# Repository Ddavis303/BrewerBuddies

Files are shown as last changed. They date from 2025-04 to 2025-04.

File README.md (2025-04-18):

# Brew Buddy – IoT Brewing Analytics System
## Overview
The Brew Buddy is an IoT-based system designed to help brewers—especially small craft and home brewers—monitor essential brewing parameters in real time. Using a combination of sensors and an Argon microcontroller, the system collects temperature, pH, specific gravity (via weight), and volume (via distance), displays the data on a web dashboard, and sends text alerts and email alerts when any readings fall outside predefined thresholds.
This project was developed as a capstone for an IoT Rapid Prototyping course and serves as a working proof-of-concept for a scalable tech solution in the brewing industry.
---
## Features
- Live data readings from brewing vessels
- Remote monitoring via dashboard
- SMS notifications when values exceed thresholds
- Simulated homebrew setup for testing and demonstration
---
## Sensors & Components
- *Argon* – Microcontroller
- **DS18B20** – Digital temperature sensor
- **pH Sensor** – Analog pH probe
- **Load Cell + HX711** – For measuring weight/specific gravity
- **VL53L0X TOF Sensor** – For estimating volume via liquid height
- **Breadboard**, **jumper wires**, **power supply**
- **Zapier** 
- **Adafruit Dashboard** 
---
## How It Works
1. Sensors are connected to the Argon and calibrated for the brewing environment.
2. Readings are taken at regular intervals and sent to the cloud.
3. A dashboard displays live data for each sensor.
4. If a reading moves outside acceptable parameters (e.g., temperature too high), an SMS alert is triggered.
---
## Setup Instructions
1. **Assemble the hardware**
Connect each sensor to the Argon as specified in the wiring diagram (included below or in the gallery).
2. **Flash the Argon*
Upload the code using Arduino IDE or PlatformIO. Install required libraries:
- `OneWire`
- `DallasTemperature`
- `HX711`
- `VL53L0X`
- Any network/messaging libraries needed
3. **Configure the backend**
- Set up a Zappier for email and text alerts
- Link your Argon code to your backend using API keys
4. **Calibrate sensors**
Run test readings and calibrate the sensors based on your brewing environment.
5. **Monitor & Brew!**
Watch your live dashboard and relax—alerts will notify you of any problems.
---
## Future Improvements
- Batch tracking and historical analytics
- Predictive alerts based on trend data
- Integration with commercial brewing systems
- Mobile app interface
---
## Credits
**Built by:**
- Dillon Davis
- Victor Roman
*Capstone Team – IoT Rapid Prototyping, April 2025*

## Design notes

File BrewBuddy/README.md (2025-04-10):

# BrewBuddy

This firmware project was created using [Particle Developer Tools](https://www.particle.io/developer-tools/) and is compatible with all [Particle Devices](https://www.particle.io/devices/).

Feel free to replace this README.md file with your own content, or keep it for reference.

## Table of Contents
- [Introduction](#introduction)
- [Prerequisites To Use This Template](#prerequisites-to-use-this-repository)
- [Getting Started](#getting-started)
- [Particle Firmware At A Glance](#particle-firmware-at-a-glance)
  - [Logging](#logging)
  - [Setup and Loop](#setup-and-loop)
  - [Delays and Timing](#delays-and-timing)
  - [Testing and Debugging](#testing-and-debugging)
  - [GitHub Actions (CI/CD)](#github-actions-cicd)
  - [OTA](#ota)
- [Support and Feedback](#support-and-feedback)
- [Version](#version)

## Introduction

For an in-depth understanding of this project template, please refer to our [documentation](https://docs.particle.io/firmware/best-practices/firmware-template/).

## Prerequisites To Use This Repository

To use this software/firmware on a device, you'll need:

- A [Particle Device](https://www.particle.io/devices/).
- Windows/Mac/Linux for building the software and flashing it to a device.
- [Particle Development Tools](https://docs.particle.io/getting-started/developer-tools/developer-tools/) installed and set up on your computer.
- Optionally, a nice cup of tea (and perhaps a biscuit).

## Getting Started

1. While not essential, we recommend running the [device setup process](https://setup.particle.io/) on your Particle device first. This ensures your device's firmware is up-to-date and you have a solid baseline to start from.

2. If you haven't already, open this project in Visual Studio Code (File -> Open Folder). Then [compile and flash](https://docs.particle.io/getting-started/developer-tools/workbench/#cloud-build-and-flash) your device. Ensure your device's USB port is connected to your computer.

3. Verify the device's operation by monitoring its logging output:
    - In Visual Studio Code with the Particle Plugin, open the [command palette](https://docs.particle.io/getting-started/developer-tools/workbench/#particle-commands) and choose "Particle: Serial Monitor".
    - Or, using the Particle CLI, execute:
    ```
    particle serial monitor --follow
    ```

4. Uncomment the code at the bottom of the cpp file in your src directory to publish to the Particle Cloud! Login to console.particle.io to view your devices events in real time.

5. Customize this project! For firmware details, see [Particle firmware](https://docs.particle.io/reference/device-os/api/introduction/getting-started/). For information on the project's directory structure, visit [this link](https://docs.particle.io/firmware/best-practices/firmware-template/#project-overview).

## Particle Firmware At A Glance

### Logging

The firmware includes a [logging library](https://docs.particle.io/reference/device-os/api/logging/logger-class/). You can display messages at different levels and filter them:

```
Log.trace("This is trace message");
Log.info("This is info message");
Log.warn("This is warn message");
Log.error("This is error message");
```

### Setup and Loop

Particle projects originate from the Wiring/Processing framework, which is based on C++. Typically, one-time setup functions are placed in `setup()`, and the main application runs from the `loop()` function.

For advanced scenarios, explore our [threading support](https://docs.particle.io/firmware/software-design/threading-explainer/).

### Delays and Timing

By default, the setup() and loop() functions are blocking whilst they run, meaning that if you put in a delay, your entire application will wait for that delay to finish before anything else can run. 

For techniques that allow you to run multiple tasks in parallel without creating threads, checkout the code example [here](https://docs.particle.io/firmware/best-practices/firmware-template/).

(Note: Although using `delay()` isn't recommended for best practices, it's acceptable for testing.)

### Testing and Debugging

For firmware testing and debugging guidance, check [this documentation](https://docs.particle.io/troubleshooting/guides/build-tools-troubleshooting/debugging-firmware-builds/).

### GitHub Actions (CI/CD)

This project provides a YAML file for GitHub, automating firmware compilation whenever changes are pushed. More details on [Particle GitHub Actions](https://docs.particle.io/firmware/best-practices/github-actions/) are available.

### OTA

To learn how to utilize Particle's OTA service for device updates, consult [this documentation](https://docs.particle.io/getting-started/cloud/ota-updates/).

Test OTA with the 'Particle: Cloud Flash' command in Visual Studio Code or the CLI command 'particle flash'!

This firmware supports binary assets in OTA packages, allowing the inclusion of audio, images, configurations, and external microcontroller firmware. More details are [here](https://docs.particle.io/reference/device-os/api/asset-ota/asset-ota/).

## Support and Feedback

For support or feedback on this template or any Particle products, please join our [community](https://community.particle.io)!

## Version

Template version 1.0.2

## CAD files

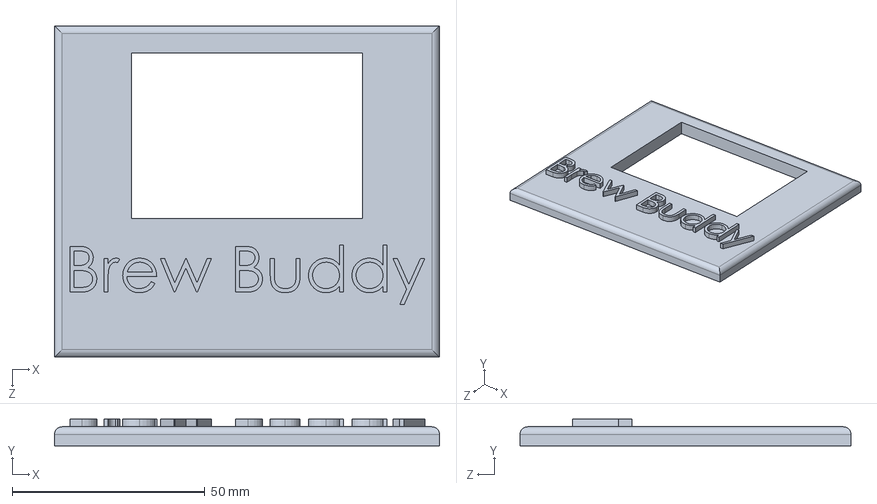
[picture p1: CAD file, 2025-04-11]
STL_SolidWorksFiles/BrewBuddyLid.SLDPRT
100.0 x 7.00 x 86.0 mm

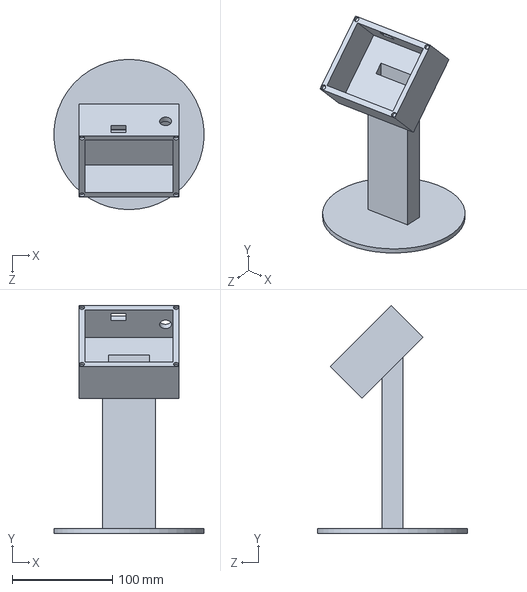
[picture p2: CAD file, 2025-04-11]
STL_SolidWorksFiles/BrewBuddyCase.SLDPRT
149.7 x 227.6 x 150.0 mm

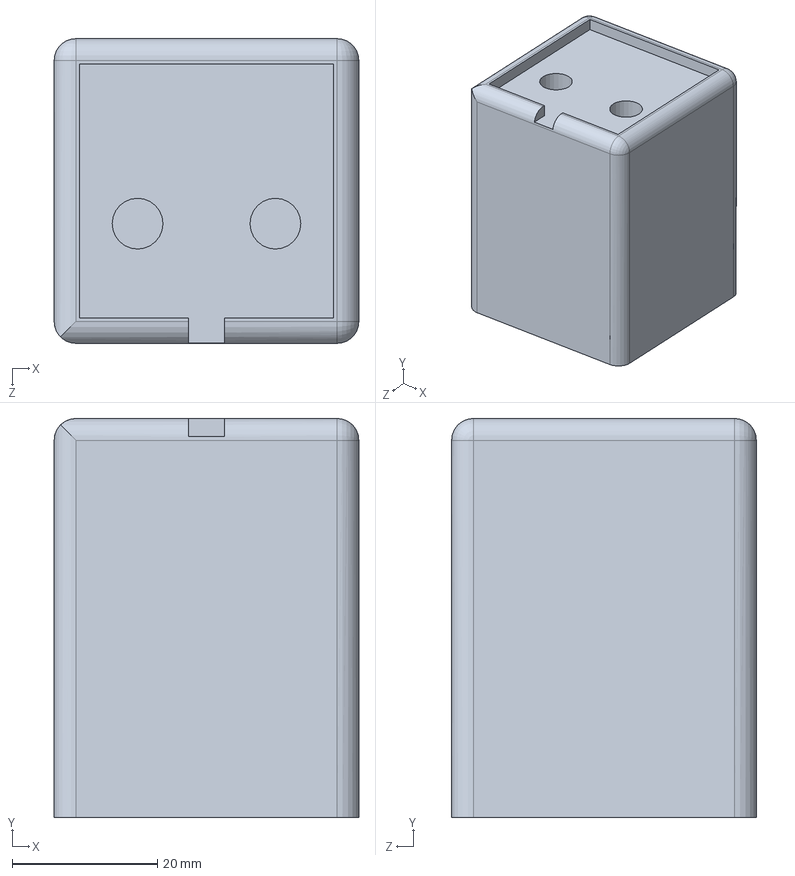
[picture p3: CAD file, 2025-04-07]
STL_SolidWorksFiles/BbLegStand.SLDPRT
42.0 x 55.0 x 42.0 mm

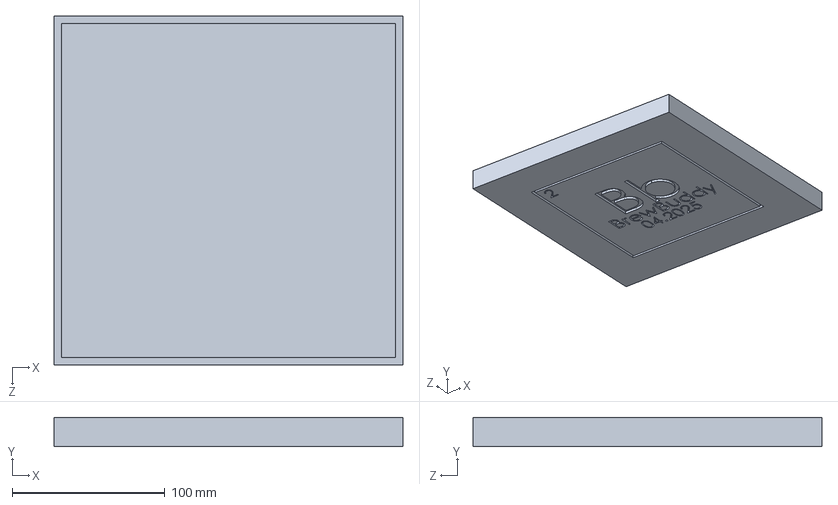
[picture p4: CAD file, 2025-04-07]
STL_SolidWorksFiles/ScaleLidBB.SLDPRT
228.6 x 19.1 x 228.6 mm

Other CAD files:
STL_SolidWorksFiles/BrewBuddyLogo.SLDPRT
STL_SolidWorksFiles/BbLegStand.3mf
STL_SolidWorksFiles/BbLegStand.STL
STL_SolidWorksFiles/BrewBuddyCase.STL
STL_SolidWorksFiles/BrewBuddyLid.STL
STL_SolidWorksFiles/ScaleLidBB.3mf
STL_SolidWorksFiles/ScaleLidBB.STL

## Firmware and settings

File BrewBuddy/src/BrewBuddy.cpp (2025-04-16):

/* 
 * Project Brew Buddy
 * Author: Victor Roman & Dillon Davis
 * Date: 4/10/25  
 * For comprehensive documentation and examples, please visit:
 * https://docs.particle.io/firmware/best-practices/firmware-template/
 */

// Include Particle Device OS APIs
#include "Particle.h"
#include "HX711.h"
#include "DS18B20.h"
#include "OneWire.h"
//#include "Adafruit_SSD1306.h"
//#include "Adafruit_GFX.h"
#include "Adafruit_MQTT.h"
#include "Adafruit_MQTT/Adafruit_MQTT_SPARK.h"
#include "Adafruit_MQTT/Adafruit_MQTT.h"
#include "credentials.h"
#include "Adafruit_VL53L0X.h"
#include "SPI.h"
#include "Adafruit_ILI9341.h"
#include "logo.h"

TCPClient theClient;
Adafruit_MQTT_SPARK mqtt(&theClient, AIO_SERVER, AIO_SERVERPORT, AIO_USERNAME, AIO_KEY);

//Variables
const int MAXRETRY = 4;
const uint32_t msSAMPLE_INTERVAL = 2500;
const uint32_t msMETRIC_PUBLISH = 10000;
uint32_t lastTime = 0;
uint32_t lastHour = 0;

const int16_t dsVCC = D3;
const int16_t dsData = D2;
//const int16_t dsGND = D4;

char szInfo[64];
double celsius;
double fahrenheit;
uint32_t msLastMetric;
uint32_t msLastSample;
const int PHPIN = A1;
float pH;
const int OLED_RESET = -1;
float acidVoltage = 2070;
float neutralVoltage = 1580;
float voltage, slope, intercept, ph = 25;

const float CALFACTOR=5.45;
const int SAMPLES=10;
float weight, rawData, calibration, liquidWeight;
int offset;

const float H20DENSITY = 1;//g/cm^3
const float RADIUS = 10.5;//cm
float gallons, volume, height, density, specificGravity;

const int TFT_DC = D5;
const int TFT_CS = D4;

// int col[8] = {tft.color565(155, 0, 50),
//               tft.color565(170, 30, 80),
//               tft.color565(195, 60, 110),
//               tft.color565(215, 90, 140),
//               tft.color565(230, 120, 170),
//               tft.color565(250, 150, 200),
//               tft.color565(255, 180, 220),
//               tft.color565(255, 210, 240)
//             };


//const float PI = 3.14159265358979323846;
//Functions
void MQTT_connect();
bool MQTT_ping();
void getTemp();
void publishData();
float getPH();
//void showmsgXY(int x, int y, int sz, const char *msg);

// Objects
DS18B20 ds18b20(dsData, true);
HX711 myScale(D15, D14);
Adafruit_VL53L0X lox = Adafruit_VL53L0X();
Adafruit_ILI9341 tft = Adafruit_ILI9341(TFT_CS, TFT_DC);
//Publish's
Adafruit_MQTT_Publish tempPub = Adafruit_MQTT_Publish(&mqtt, AIO_USERNAME "/feeds/temp");
Adafruit_MQTT_Publish phPub = Adafruit_MQTT_Publish(&mqtt, AIO_USERNAME "/feeds/ph");
Adafruit_MQTT_Publish specificGPub = Adafruit_MQTT_Publish(&mqtt, AIO_USERNAME "/feeds/specificg");
Adafruit_MQTT_Publish gallonPub = Adafruit_MQTT_Publish(&mqtt, AIO_USERNAME "/feeds/barrels");

SYSTEM_MODE(AUTOMATIC);

// Run the application and system concurrently in separate threads
SYSTEM_THREAD(ENABLED);

void setup()
{
  Serial.begin(9600);
  //delay(3000);
  WiFi.clearCredentials();
  WiFi.setCredentials("CODA-1B30", "2512070C3758");
  //WiFi.setCredentials("DDCIOT", "ddcIOT2020");
  WiFi.on();
  WiFi.connect();
  while(WiFi.connecting()) {
    Serial.printf(".");
  }
  Serial.printf("\n\n");
  
  //ToF Setup
  Serial.println("Adafruit VL53L0X test");
  if (!lox.begin()) {
    Serial.println(F("Failed to boot VL53L0X"));
    while(1);
  }

  //Screen Setup
   tft.begin();
  tft.fillScreen(ILI9341_BLACK);
  tft.setRotation(1);
  //Show Logo
  tft.drawBitmap(0, 0, logo, 320, 240, ILI9341_GREEN);
  delay(3000);
  tft.fillScreen(ILI9341_BLACK);


  pinMode(dsVCC, OUTPUT);
  digitalWrite(dsVCC, HIGH);
  pinMode(PHPIN, INPUT);
  
  // Add initialization check
  Serial.println("Initializing sensor...");

  //Scale Setup
  myScale.set_scale();//Initalize loadcell
  delay(6000);//let loadcell settle
 
  myScale.tare();//set the tare weight
  myScale.set_scale(CALFACTOR);//adjust when calibrating scale to desired units
  delay(1000);

  
}

void loop()
{
  //MQTT Connect
  MQTT_connect();
  MQTT_ping();

  //ToF
  VL53L0X_RangingMeasurementData_t measure;
    
  Serial.print("\nReading a measurement... ");
  lox.rangingTest(&measure, false); // pass in 'true' to get debug data printout!

  if (measure.RangeStatus != 4) {  // phase failures have incorrect data
    Serial.print("\nDistance (mm): "); Serial.println(measure.RangeMilliMeter);
  } else {
    Serial.println(" out of range ");
  }

  //Scale
  weight = myScale.get_units(SAMPLES);
  gallons = 3785.0 / weight;
  Serial.printf("Weight: %f\n", weight);
  // liquidWeight = weight - 643;
  // Serial.printf("Liquid Weight: %f\n", liquidWeight);
  delay(2000);
  
  // rawData = myScale.get_value(SAMPLES);
  // offset = myScale.get_offset();
  // calibration = myScale.get_scale();

  //Specific Gravity
  height = 24 - (measure.RangeMilliMeter/10);
  volume = PI * pow(RADIUS,2) * height;
  Serial.printf("Height: %f\n", height);
  Serial.printf("Volume: %f\n", volume);
  density = weight / volume;
  Serial.printf("Density: %f\n", density);
  specificGravity = density / H20DENSITY;
  Serial.printf("Specific Gravity: %f\n", specificGravity);

  //Check Temperature
  if (millis() - msLastSample >= msSAMPLE_INTERVAL)
  {
    getTemp();
  }


  // //Check pH
  
   pH = getPH();


  //Print to tft
  tft.fillScreen(ILI9341_BLACK);
  tft.setCursor(0, 0);
  tft.setTextColor(ILI9341_GREEN);
  tft.setTextSize(4);
  tft.printf("  Brew Buddy\n");
  tft.setTextSize(3);
  tft.printf("\nTemp: %0.2fF\n", fahrenheit);
  tft.printf("pH: %0.2f\n", pH);
  tft.printf("SG: %0.5f\n", specificGravity);
  tft.printf("Weight: %0.2f\n", weight);
  tft.printf("Distance: %0.2f\n", height);
  tft.printf("Gallons: %0.2f\n", gallons);

  //publish to Adafruit every minute
  if((millis()-lastTime > 60000)) {
    if(mqtt.Update()) {
        tempPub.publish(fahrenheit);
        Serial.printf("Publishing %0.2f \n",fahrenheit);
      } 
    lastTime = millis();
  }

  //Publish to Adafruit every hour
  if((millis()-lastHour) > 3600000){
    phPub.publish(pH);
    Serial.printf("Publishing %0.2f \n",pH);
    specificGPub.publish(specificGravity);
    Serial.printf("Publishing %0.2f \n",specificGravity); 
    gallonPub.publish(gallons);
    Serial.printf("Publishing %0.2f \n",gallons);
  }
}

void publishData()
{
  sprintf(szInfo, "%2.2f", fahrenheit);
  Particle.publish("dsTmp", szInfo, PRIVATE);
  msLastMetric = millis();
}

void getTemp()
{
  float _temp;
  int i = 0;

  Serial.println("Starting temperature reading...");

  // Longer delay to ensure sensor is ready
  delay(2000);

  do
  {
    _temp = ds18b20.getTemperature();
    Serial.printlnf("Attempt %d: Raw temperature value: %f", i + 1, _temp);
    Serial.printlnf("CRC Check: %s", ds18b20.crcCheck() ? "PASS" : "FAIL");

    // Print the actual value before conversion
    Serial.printlnf("Raw value before conversion: %f", _temp);

    if (!ds18b20.crcCheck())
    {
      Serial.println("Waiting 100ms before next attempt...");
      delay(100);
    }
  } while (!ds18b20.crcCheck() && MAXRETRY > i++);

  if (i < MAXRETRY)
  {
    // Manual temperature conversion
    if (!isnan(_temp) && _temp != 0.0)
    { // Also check for zero
      celsius = _temp;
      fahrenheit = celsius * 9.0 / 5.0 + 32.0;
      Serial.printlnf("Success! Temperature: %f°F (%f°C)", fahrenheit, celsius);
    }
    else
    {
      celsius = fahrenheit = NAN;
      Serial.println("ERROR: Invalid temperature reading");
      Serial.println("Raw value was invalid or zero");
    }
  }
  else
  {
    celsius = fahrenheit = NAN;
    Serial.println("ERROR: Invalid reading after maximum retries");
    Serial.println("Please check:");
    Serial.println("1. 4.7kΩ pull-up resistor between D0 and VCC");
    Serial.println("2. All connections are secure");
    Serial.println("3. Sensor is properly powered (3.3V)");
  }
  msLastSample = millis();
}

// Function to connect and reconnect as necessary to the MQTT server.
// Should be called in the loop function and it will take care if connecting.
void MQTT_connect() {
  int8_t ret;
 
  // Return if already connected.
  if (mqtt.connected()) {
    return;
  }
 
  Serial.print("Connecting to MQTT... ");
 
  while ((ret = mqtt.connect()) != 0) { // connect will return 0 for connected
       Serial.printf("Error Code %s\n",mqtt.connectErrorString(ret));
       Serial.printf("Retrying MQTT connection in 5 seconds...\n");
       mqtt.disconnect();
       delay(5000);  // wait 5 seconds and try again
  }
  Serial.printf("MQTT Connected!\n");
}

bool MQTT_ping() {
  static unsigned int last;
  bool pingStatus;

  if ((millis()-last)>120000) {
      Serial.printf("Pinging MQTT \n");
      pingStatus = mqtt.ping();
      if(!pingStatus) {
        Serial.printf("Disconnecting \n");
        mqtt.disconnect();
      }
      last = millis();
  }
  return pingStatus;
}

float getPH(){
  
  voltage = analogRead(PHPIN)/4095.0*3300; //Read the voltage
  slope = (7.0-4.0)/((neutralVoltage-1500)/3.0 - (acidVoltage-1500)/3.0); 
  intercept = 7.0 - slope*(neutralVoltage-1500)/3.0;
  ph = slope*(voltage-1500)/3.0+intercept; // y = mx+b
  Serial.printf("\nVoltage: %0.4f", voltage/1000.0);
  Serial.printf("\npH: %0.4f", ph);
  // display.setTextSize(2);
  // display.setTextColor(WHITE);
  // display.setCursor(0,0);
  // display.clearDisplay();
  // display.printf("\nV: %0.4f", voltage/1000.0);
  // display.printf("\npH: %0.4f", ph);
  // display.display();
  return ph;
}

// void showmsgXY(int x, int y, int sz, const char *msg)
// {
//   int16_t x1, y1;
//   uint16_t wid, ht;


//   tft.setFont(SansSerifBold9pt7b);
//   tft.setCursor(x, y);
//   tft.setTextColor(0x0000);
//   tft.setTextSize(sz);
//   tft.print(msg);
// }

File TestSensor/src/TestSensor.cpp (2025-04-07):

#include "Particle.h"
#include "OneWire.h"

// Photon 2 pin assignments
const int16_t dsVCC = D6;  // Power pin
const int16_t dsData = D7; // Data pin
const int16_t dsGND = D8;  // Ground pin

// Initialize OneWire directly
OneWire oneWire(dsData);

// Device address
uint8_t deviceAddress[8];
bool deviceFound = false;

// Function prototypes
void readTemperature();
bool initializeSensor();
uint8_t crc8(uint8_t *addr, uint8_t len);
bool resetOneWire();
bool readBit();
void writeBit(uint8_t bit);
void writeByte(uint8_t data);
uint8_t readByte();
void releaseBus();

void setup() {
  Serial.begin(115200);
  while(!Serial.isConnected()) {
    delay(100);
  }
  
  Serial.println("\n=== DS18B20 Initialization ===");
  Serial.printf("VCC Pin: %d, Data Pin: %d, GND Pin: %d\n", dsVCC, dsData, dsGND);
  
  // Configure pins for Photon 2
  pinMode(dsGND, OUTPUT);
  digitalWrite(dsGND, LOW);
  pinMode(dsVCC, OUTPUT);
  digitalWrite(dsVCC, HIGH);
  pinMode(dsData, INPUT);  // Start as input
  
  // Give more time for power to stabilize
  Serial.println("Waiting for power to stabilize...");
  delay(3000);
  
  // Check voltage levels
  Serial.println("\nChecking voltage levels:");
  int vccLevel = digitalRead(dsVCC);
  int gndLevel = digitalRead(dsGND);
  int dataLevel = digitalRead(dsData);
  
  Serial.printf("VCC: %d, GND: %d, Data: %d\n", vccLevel, gndLevel, dataLevel);
  
  if (vccLevel != HIGH || gndLevel != LOW) {
    Serial.println("ERROR: Power configuration issue!");
    Serial.println("VCC should be HIGH and GND should be LOW");
    return;
  }
  
  // Try to initialize the sensor
  if (initializeSensor()) {
    deviceFound = true;
  } else {
    deviceFound = false;
  }
}

void releaseBus() {
  pinMode(dsData, INPUT);
  delayMicroseconds(5);
}

bool resetOneWire() {
  pinMode(dsData, OUTPUT);
  digitalWrite(dsData, LOW);
  delayMicroseconds(480);
  releaseBus();
  delayMicroseconds(70);
  return (digitalRead(dsData) == LOW);
}

bool readBit() {
  pinMode(dsData, OUTPUT);
  digitalWrite(dsData, LOW);
  delayMicroseconds(1);
  releaseBus();
  delayMicroseconds(15);
  bool bit = digitalRead(dsData);
  delayMicroseconds(45);
  return bit;
}

void writeBit(uint8_t bit) {
  pinMode(dsData, OUTPUT);
  digitalWrite(dsData, LOW);
  delayMicroseconds(bit ? 6 : 60);
  releaseBus();
  delayMicroseconds(64);
}

void writeByte(uint8_t data) {
  for (uint8_t i = 0; i < 8; i++) {
    writeBit(data & 0x01);
    data >>= 1;
  }
  releaseBus();
}

uint8_t readByte() {
  uint8_t data = 0;
  for (uint8_t i = 0; i < 8; i++) {
    data >>= 1;
    if (readBit()) {
      data |= 0x80;
      Serial.print("1");
    } else {
      Serial.print("0");
    }
  }
  Serial.println();
  releaseBus();
  return data;
}

bool initializeSensor() {
  Serial.println("\nAttempting to initialize sensor...");
  
  if (resetOneWire()) {
    Serial.println("Presence pulse detected!");
    
    // Skip ROM command
    Serial.println("Sending Skip ROM command (0xCC)...");
    writeByte(0xCC);
    delayMicroseconds(100);
    
    // Start temperature conversion
    Serial.println("Sending Convert T command (0x44)...");
    writeByte(0x44);
    
    // Wait for conversion
    Serial.println("Waiting for conversion...");
    delay(750);
    
    // Reset and skip ROM again
    Serial.println("Resetting bus...");
    resetOneWire();
    
    Serial.println("Sending Skip ROM command (0xCC)...");
    writeByte(0xCC);
    delayMicroseconds(100);
    
    // Read scratchpad
    Serial.println("Sending Read Scratchpad command (0xBE)...");
    writeByte(0xBE);
    delayMicroseconds(100);
    
    // Read all 9 bytes of scratchpad
    uint8_t data[9];
    Serial.println("Reading scratchpad data (bit by bit):");
    for(int i = 0; i < 9; i++) {
      Serial.printf("Byte %d: ", i);
      data[i] = readByte();
      Serial.printf(" = 0x%02X\n", data[i]);
      delayMicroseconds(100);
    }
    
    // Print raw data
    Serial.println("Raw scratchpad data:");
    for(int i = 0; i < 9; i++) {
      Serial.printf("%02X ", data[i]);
    }
    Serial.println();
    
    // Calculate temperature (LSB is first byte)
    int16_t rawTemp = (data[1] << 8) | data[0];
    float tempC = (float)rawTemp / 16.0;
    float tempF = tempC * 9.0 / 5.0 + 32.0;
    
    Serial.printlnf("Temperature: %f°F (%f°C)", tempF, tempC);
    Serial.printf("Raw temperature value: 0x%04X\n", rawTemp);
    
    // Verify CRC
    uint8_t crc = crc8(data, 8);
    if (crc == data[8]) {
      Serial.println("CRC check passed!");
      return true;
    } else {
      Serial.printf("CRC check failed! Calculated: 0x%02X, Received: 0x%02X\n", crc, data[8]);
      return false;
    }
  } else {
    Serial.println("No presence pulse detected!");
  }
  
  Serial.println("\nTroubleshooting steps:");
  Serial.println("1. Check if 4.7kΩ pull-up resistor is connected between D7 and VCC");
  Serial.println("2. Measure voltage between VCC and GND - should be 3.3V");
  Serial.println("3. Check all connections are secure");
  Serial.println("4. Try a different data pin");
  Serial.println("5. Verify sensor is not damaged");
  Serial.println("6. Try power cycling the Photon 2");
  Serial.println("7. Check if the sensor is getting warm (indicating power)");
  return false;
}

// CRC8 calculation function
uint8_t crc8(uint8_t *addr, uint8_t len) {
  uint8_t crc = 0;
  while (len--) {
    uint8_t inbyte = *addr++;
    for (uint8_t i = 8; i; i--) {
      uint8_t mix = (crc ^ inbyte) & 0x01;
      crc >>= 1;
      if (mix) crc ^= 0x8C;
      inbyte >>= 1;
    }
  }
  return crc;
}

void loop() {
  if (deviceFound) {
    readTemperature();
  } else {
    Serial.println("\nTrying to detect device again...");
    if (initializeSensor()) {
      deviceFound = true;
    }
  }
  delay(2000);
}
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

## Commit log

2025-04-08 Weight Sensor WIP
    [ScaleLidBB.3mf]
2025-04-10 ToF Sensor
2025-04-11 Case Design
    [BrewBuddyCase.SLDPRT, BrewBuddyCase.STL, BrewBuddyLid.SLDPRT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]
